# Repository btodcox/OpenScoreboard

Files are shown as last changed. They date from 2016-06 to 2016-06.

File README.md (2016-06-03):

#OpenScoreboard
## An Open Source Wireless Swimming Scoreboard that can be easily modified for other sports

OpenScoreboard is an Eagle Scout Project completed by David Cox in 2014.  The beneficiary/sponsoring organization was the Gleannloch Gators Swim Team.

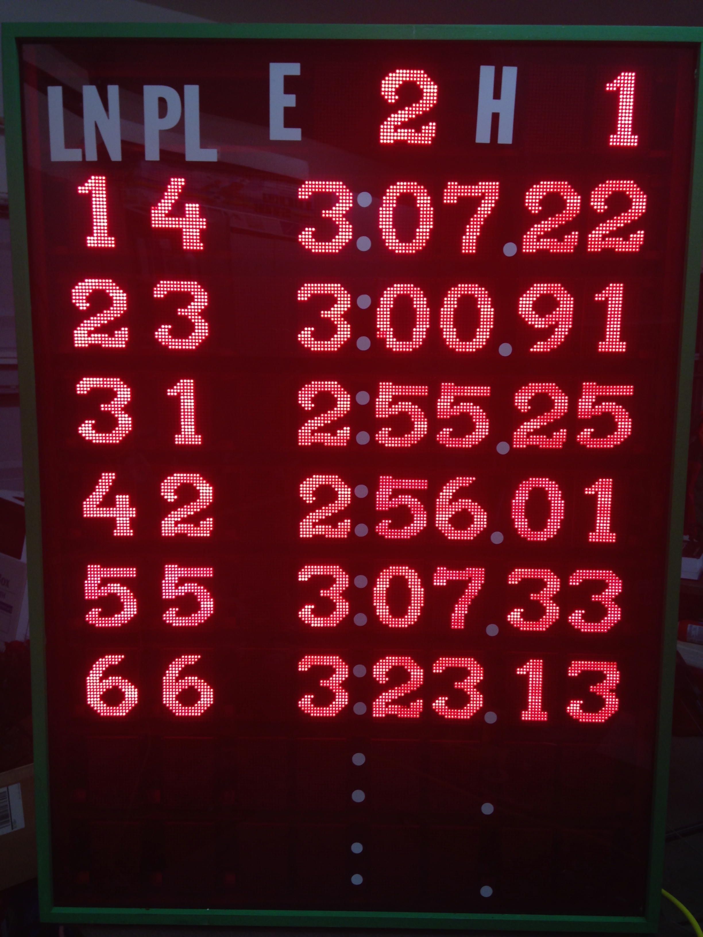
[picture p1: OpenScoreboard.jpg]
OpenScoreboard


The scoreboard hardware is designed around an Arduino derivative known as the Moteino from Felix Rusu at lowpowerlabs.com.  A program on a host PC implements a filewatcher.  When a new set of times is written to the hard drive of the host PC at the end of a completed heat, the program parses the times, calculates the swimmers tentative official time, determines the order of finish, and passes the data to a USB attached Moteino.  This Moteino then passes the information wirelessly to the scoreboard where it is displayed.  The results of a given heat are displayed until the next heat completes.  While this is a bit different than typical swimming scoreboards (which reset as soon as the next heat starts), it allows the coaches and swimmers to focus on the logistics of finishing one heat and beginning the next heat without having to hurriedly view the scoreboard.

License Info:

<br /><span xmlns:dct="http://purl.org/dc/terms/" property="dct:title">OpenScoreboard</span> by <a xmlns:cc="http://creativecommons.org/ns#" href="https://github.com/btodcox/Scoreboard" property="cc:attributionName" rel="cc:attributionURL">B Tod Cox & David Cox</a> is licensed under a <a rel="license" href="http://creativecommons.org/licenses/by-sa/4.0/">Creative Commons Attribution-ShareAlike 4.0 International License</a>. A copy of the license is available at the provided link. 

Portions of this project leverages other projects; attributions are included in the repository.

## Bill of Materials for 8-Lane Wireless Scoreboard

The estimated total cost for an 8-lane OpenScoreboard is ~$2500.

Custom PCA (a total of N+1 Custom PCAs are needed for an N-lane scoreboard)

*   9x Custom Scoreboard PCB (Eagle CAD files included in repository)
*   18X 74AHCT245D Octal Transceiver SOIC-20 ([Mouser 771-AHCT245D118](http://www.mouser.com/Search/ProductDetail.aspx?R=74AHCT245D,118virtualkey66800000virtualkey771-AHCT245D118))
*   2.1mm x 5.5mm DC barrel jack ([Mouser 163-7620E-E](http://www.mouser.com/Search/ProductDetail.aspx?R=163-7620E-Evirtualkey11180000virtualkey163-7620E-E))
*   18X dual row 2x5 0.1" female header ([Mouser 571-215309-5](http://www.mouser.com/Search/ProductDetail.aspx?R=215309-5virtualkey57100000virtualkey571-215309-5))
*   ~250X Breakaway 0.1" Male Headers ([Mouser 649-54101-S08-00](http://www.mouser.com/Search/ProductDetail.aspx?R=54101-S08-00virtualkey64910000virtualkey649-54101-S08-00))
*   18X 0.1uF 16V 10% X7R 0603 capacitor ([Mouser 80-C0603C104K4R7411](http://www.mouser.com/Search/ProductDetail.aspx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))

Electronic Parts

*   9X [Moteino Arduino clone with tranceiver and flash](http://lowpowerlab.com/moteino/#pinout)
*   1X [USB Moteino with transciever and no flash](http://lowpowerlab.com/moteino/#pinout)
*   68X 16x24 Red LED Matrix Panel Chainable HT1632C Driver ([Adafruit part #555](http://www.adafruit.com/products/555))
*   408X 1206 4RNet 27 Ohm 5% (to increase brightness of LED panels) ([Mouser 667-EXB-38V270JV](http://www.mouser.com/Search/ProductDetail.aspx?R=EXB-38V270JVvirtualkey66720000virtualkey667-EXB-38V270JV))
*   84X 2x5 IDC ribbon cable male connectors (need a different part number as I don't like the ones that I last ordered from Mouser)
*   ~50ft Flat Cables 28 AWG Ribbon .050 Zip 10 Cond ([Mouser 523-191-2801-110FT](http://www.mouser.com/Search/ProductDetail.aspx?R=191-2801-110FTvirtualkey52320000virtualkey523-191-2801-110FT))
*   4X 5V 10A switching power supply ([Adafruit part #658](http://www.adafruit.com/product/658))
*   3X 2-Way 2.1mm DC Barrel Jack Splitter Squid ([Adafruit part #1351](http://www.adafruit.com/product/1351))
*   Heavy gauge wire for connecting three lanes together (could not find a squid splitter long enough for Event/Heat + 2 lanes)
*   Surge protector
*   Mini-USB to USB cable
*   Small plastic box for USB Moteino

Case/Mechanical Structure

*   18X 3/4 in. x 1/2 in. x 36 in. Aluminum Flat Angle with 1/16 in. Thick ([Home Depot](http://www.homedepot.com/p/Crown-Bolt-3-4-in-x-1-2-in-x-36-in-Aluminum-Flat-Angle-with-1-16-in-Thick-43650/202183475)/Lowes/etc)
*   2X Steelworks 6-ft L x -3/4-in W x -3/4-in H Aluminum Plain Square Tube ([Lowes](http://www.lowes.com/pd_215691-37672-11388_0__)/Home Depot/etc)
*   Red Cast Acrylic (Aero-Shield Plastics in Houston)
*   1x6 Poplar S4S boards for case (Home Depot/Lowes/etc)
*   272X 4-40 x 1" female/female hex binding post ([Mouser 534-2205](http://www.mouser.com/Search/ProductDetail.aspx?R=2205virtualkey53400000virtualkey534-2205))
*   544x 4-40 3/8" phillips head screws ([Mouser 534-9901](http://www.mouser.com/Search/ProductDetail.aspx?R=9901virtualkey53400000virtualkey534-9901))
*   1-1/4 in. Coarse Zinc-Plated Steel Square-Head Pocket Screws (100-Pack) ([Home Depot](http://www.homedepot.com/p/Kreg-1-1-4-in-Coarse-Zinc-Plated-Steel-Square-Head-Pocket-Screws-100-Pack-SML-C125-100/100572559))
*   1X 1/4 in. 5 ft. x 5ft Baltic Birch Plywood-Grade A ([Houston Hardwoods](http://www.houstonhardwoods.net/))
*   Paint for wood (less than 1/2 pint is needed to cover wood)
*   Exterior grade urethane for back of plywood
*   Black matte spray paint for interior of plywood and aluminum

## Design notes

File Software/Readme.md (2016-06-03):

# Scoreboard code

* Host PC code is written in C# and is provided as a Visual Studio project.
* Moteino code compiles with the standard Arduino Development Environment.
    * Installation of appropriate libraries from lowpowerlabs github respositories is required.

* Preliminaries for Moteinos:
	* Clear eeprom on each Moteino used for lane displays
	* Program location 0 of eeprom with "address" of lane for Moteinos for each lane
    	* Address 0 is event/heat display
    	* Addresses 1-10 are Lanes 1-10, respectively
	* Base code goes on USB Moteino
	* RemoteHEWP code goes on Moteinos for each lane

## Programming the Moteinos in Scoreboard

* After initial programming of Moteinos with RemoteHEWP program, it is possible to wirelessly program them Moteinos WITHOUT disassembling the Scoreboard.  
* Wireless programming requires that a SPIFlash be installed on all Moteinos in the Scoreboard.
* More information about wireless programming is available at [lowpowerlabs.com](http://lowpowerlab.com/blog/category/moteino/wireless-programming/).

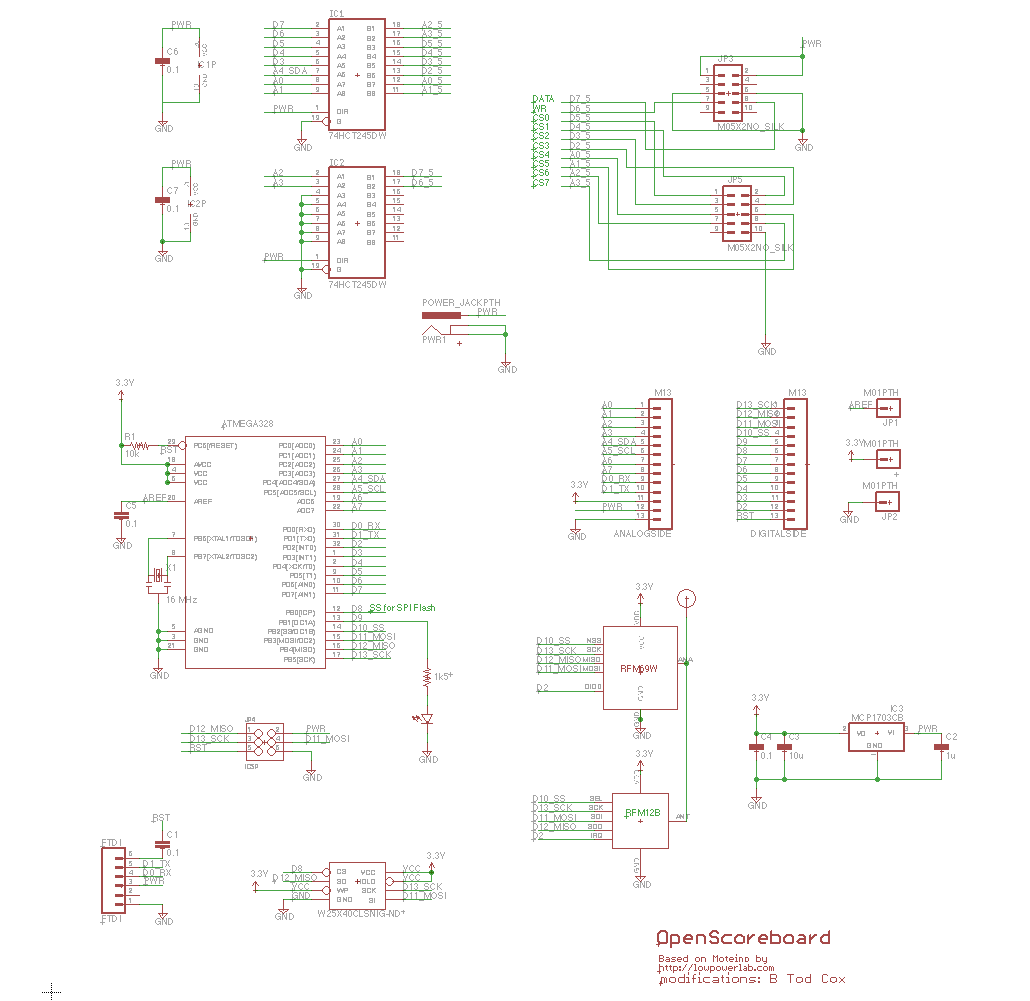
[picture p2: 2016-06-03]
Hardware/OpenScoreboard_PCB/OpenScoreboard.png

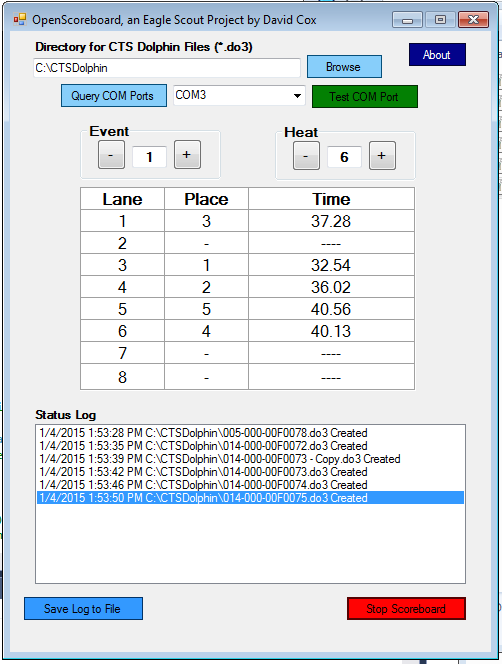
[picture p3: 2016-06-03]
Pics/OpenScoreboardHost.png

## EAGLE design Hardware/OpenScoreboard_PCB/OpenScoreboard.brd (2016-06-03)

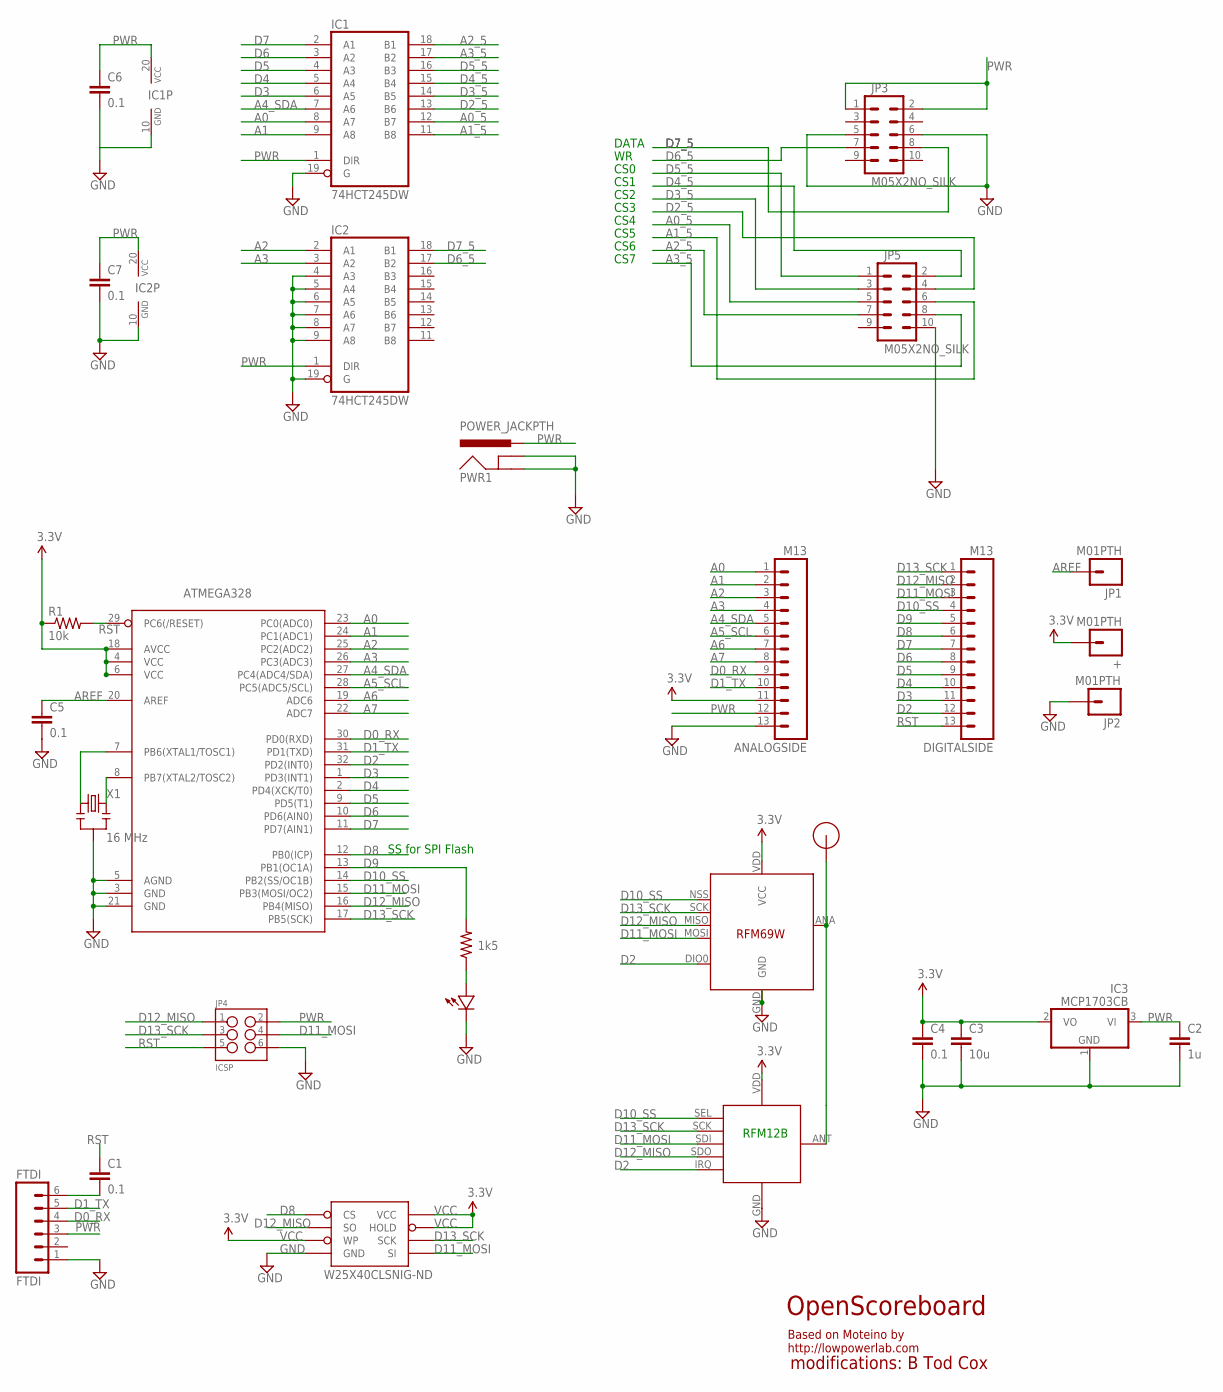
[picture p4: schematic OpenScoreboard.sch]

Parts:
+: M01PTH; 1X01
ANALOGSIDE: M13; 1X13
ATMEGA328: ATMega-328; TQFP32-08
C1, C4, C5, C6, C7: 0.1; 0603-CAP
C2: 1u; 0603-CAP
C3: 10u; 0805-CAP
DIGITALSIDE: M13; 1X13
FTDI: FTDI; 1X06
IC1, IC2: 74HCT245DW; SO20W
IC3: MCP1703CB; SOT23
JP1, JP2: M01PTH; 1X01
JP3, JP5: M05X2NO_SILK; 2X5_NOSILK
JP4: ICSP; 2X3_POGO
PWR1: POWER_JACKPTH; POWER_JACK_PTH
R1: 10k; 0603-RES
R2: 1k5; 0603-RES
RFM12B: RFM12B_MINPADS; RFM12B-MINPADS
U$1: RFM12B_ANTENNA; RFM12B-ANTENNA
U$2: LED0603; 0603-LED
U$5: RFM69; RFM69W-MINPADS
W25X40CLSNIG-ND: AT25F512BWIDE_5.3MM; SO08WIDE
X1: 16 MHz; RESONATOR-SMD

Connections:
A0: ANALOGSIDE.1, ATMEGA328.23 (PC0(ADC0)), IC1.8 (A7)
A0_5: IC1.12 (B7), JP5.5
A1: ANALOGSIDE.2, ATMEGA328.24 (PC1(ADC1)), IC1.9 (A8)
A1_5: IC1.11 (B8), JP5.6
A2: ANALOGSIDE.3, ATMEGA328.25 (PC2(ADC2)), IC2.2 (A1)
A2_5: IC1.18 (B1), JP5.7
A3: ANALOGSIDE.4, ATMEGA328.26 (PC3(ADC3)), IC2.3 (A2)
A3_5: IC1.17 (B2), JP5.8
A4_SDA: ANALOGSIDE.5, ATMEGA328.27 (PC4(ADC4/SDA)), IC1.7 (A6)
A5_SCL: ANALOGSIDE.6, ATMEGA328.28 (PC5(ADC5/SCL))
A6: ANALOGSIDE.7, ATMEGA328.19 (ADC6)
A7: ANALOGSIDE.8, ATMEGA328.22 (ADC7)
AREF: ATMEGA328.20 (AREF), C5.1, JP1.1
D0_RX: ANALOGSIDE.9, ATMEGA328.30 (PD0(RXD)), FTDI.4
D1_TX: ANALOGSIDE.10, ATMEGA328.31 (PD1(TXD)), FTDI.5
D2: ATMEGA328.32 (PD2(INT0)), DIGITALSIDE.12, RFM12B.IRQ, U$5.DIO0
D2_5: IC1.13 (B6), JP5.4
D3: ATMEGA328.1 (PD3(INT1)), DIGITALSIDE.11, IC1.6 (A5)
D3_5: IC1.14 (B5), JP5.3
D4: ATMEGA328.2 (PD4(XCK/T0)), DIGITALSIDE.10, IC1.5 (A4)
D4_5: IC1.15 (B4), JP5.2
D5: ATMEGA328.9 (PD5(T1)), DIGITALSIDE.9, IC1.4 (A3)
D5_5: IC1.16 (B3), JP5.1
D6: ATMEGA328.10 (PD6(AIN0)), DIGITALSIDE.8, IC1.3 (A2)
D6_5: IC2.17 (B2), JP3.7
D7: ATMEGA328.11 (PD7(AIN1)), DIGITALSIDE.7, IC1.2 (A1)
D7_5: IC2.18 (B1), JP3.8
D8: ATMEGA328.12 (PB0(ICP)), DIGITALSIDE.6, W25X40CLSNIG-ND.1 (CS)
D9: ATMEGA328.13 (PB1(OC1A)), DIGITALSIDE.5, R2.2
D10_SS: ATMEGA328.14 (PB2(SS/OC1B)), DIGITALSIDE.4, RFM12B.SEL, U$5.NSS (SEL)
D11_MOSI: ATMEGA328.15 (PB3(MOSI/OC2)), DIGITALSIDE.3, JP4.P$4 (4), RFM12B.SDI (SDI/MOSI), U$5.MOSI, W25X40CLSNIG-ND.5 (SI)
D12_MISO: ATMEGA328.16 (PB4(MISO)), DIGITALSIDE.2, JP4.P$1 (1), RFM12B.SDO (SDO/MISO), U$5.MISO, W25X40CLSNIG-ND.2 (SO)
D13_SCK: ATMEGA328.17 (PB5(SCK)), DIGITALSIDE.1, JP4.P$3 (3), RFM12B.SCK, U$5.SCK, W25X40CLSNIG-ND.6 (SCK)
GND: ANALOGSIDE.13, ATMEGA328.3 (GND), ATMEGA328.5 (AGND), ATMEGA328.21 (GND), C2.2, C3.2, C4.2, C5.2, C6.2, C7.2, FTDI.1, IC1.10 (GND), IC1.19 (G), IC2.4 (A3), IC2.5 (A4), IC2.6 (A5), IC2.7 (A6), IC2.8 (A7), IC2.9 (A8), IC2.10 (GND), IC2.19 (G), IC3.1 (GND), JP2.1, JP3.5, JP3.6, JP4.P$6 (6), JP5.10, PWR1.GND, PWR1.GNDBREAK, RFM12B.GND, U$2.MINUS, U$5.GND, W25X40CLSNIG-ND.4 (GND), X1.2
unnamed: ATMEGA328.7 (PB6(XTAL1/TOSC1)), X1.1
unnamed: R2.1, U$2.PLUS
unnamed: RFM12B.ANT, U$1.P$1, U$5.ANA (ANT)
unnamed: C1.2, FTDI.6
unnamed: ATMEGA328.8 (PB7(XTAL2/TOSC2)), X1.3
PWR: ANALOGSIDE.12, C2.1, C6.1, C7.1, FTDI.3, IC1.1 (DIR), IC1.20 (VCC), IC2.1 (DIR), IC2.20 (VCC), IC3.3 (VI), JP3.1, JP3.2, JP4.P$2 (2), PWR1.PWR
RST: ATMEGA328.29 (PC6(/RESET)), C1.1, DIGITALSIDE.13, JP4.P$5 (5), R1.2
VCC: +.1, ANALOGSIDE.11, ATMEGA328.4 (VCC), ATMEGA328.6 (VCC), ATMEGA328.18 (AVCC), C3.1, C4.1, IC3.2 (VO), R1.1, RFM12B.VDD, U$5.VDD (VCC), W25X40CLSNIG-ND.3 (WP), W25X40CLSNIG-ND.7 (HOLD), W25X40CLSNIG-ND.8 (VCC)

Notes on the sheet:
OpenScoreboard
modifications: B Tod Cox
Based on Moteino by http://lowpowerlab.com
RFM12B
SS for SPI Flash
DATA
CS0
CS1
CS2
CS3
CS4
CS5
CS6
CS7

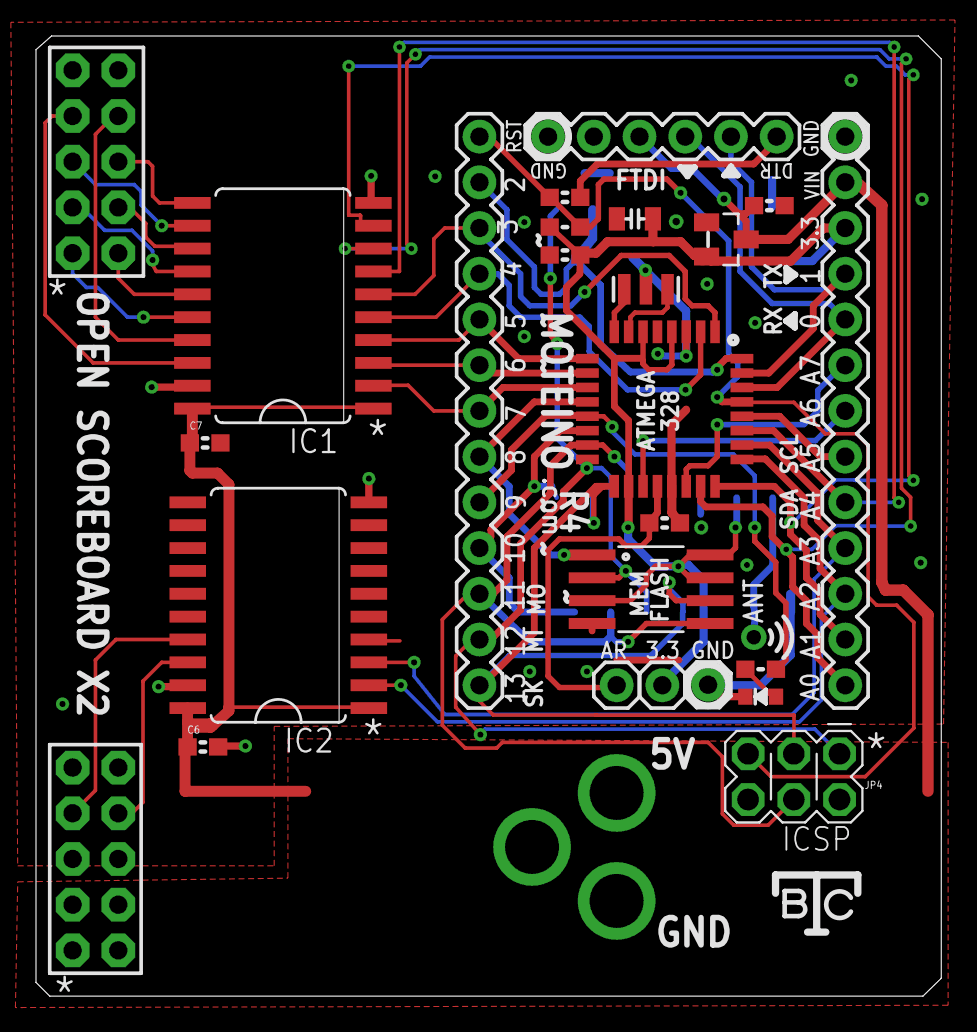
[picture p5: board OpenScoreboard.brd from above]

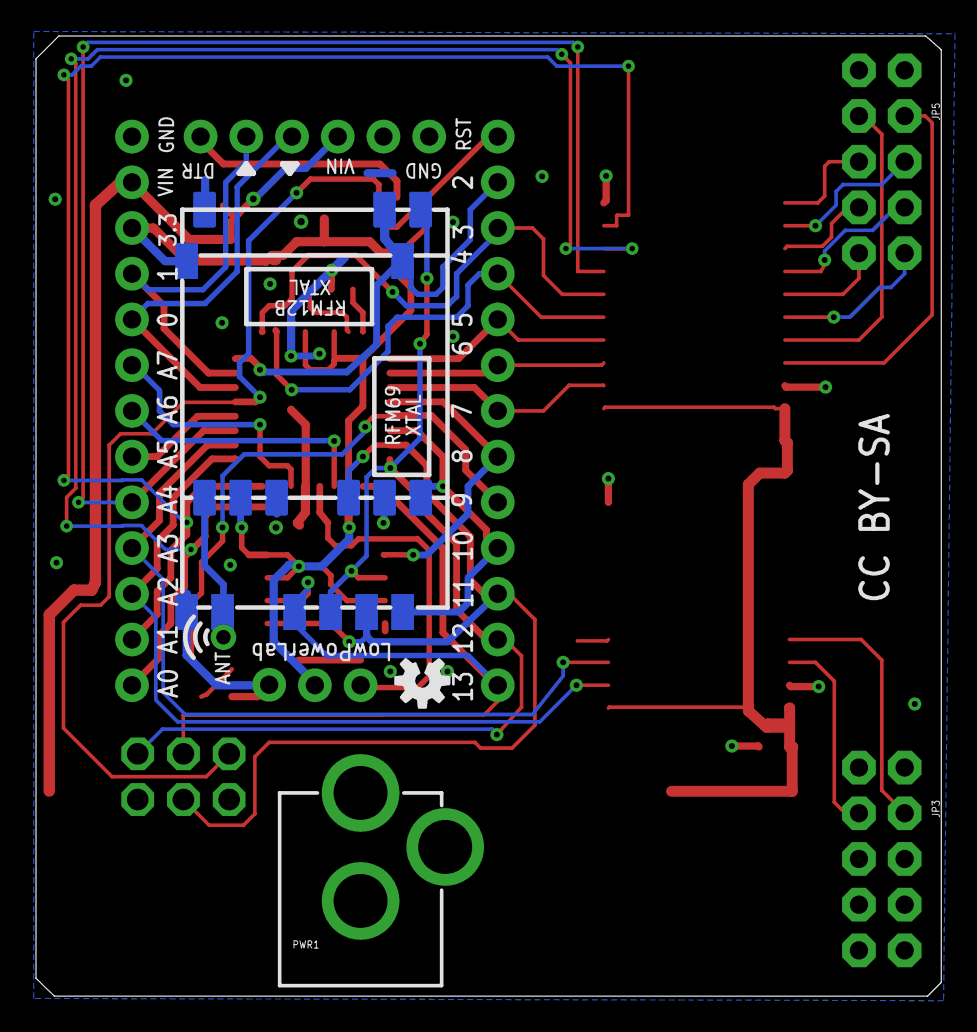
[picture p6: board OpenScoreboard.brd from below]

Board: 2 copper layers, 50.3 x 53.3 mm, 30 parts (6 on the bottom side), 42 nets.

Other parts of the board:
U$3: OSHW-LOGO-S

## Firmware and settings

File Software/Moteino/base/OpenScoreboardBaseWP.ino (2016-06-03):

/*
 * OpenScoreboard is an Eagle Scout project by David Cox
 *
 *
 * portions of code are:
 * Copyright (c) 2013 by Felix Rusu <felix@lowpowerlab.com>
 *
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
 *
 * additional code for a scoreboard is 
 * Copyright (c) 2014-15 by B Tod Cox & David Cox  
 *  all rights reserved.
 
// This sketch is an example of how wireless programming can be achieved with a Moteino
// that was loaded with a custom 1k Optiboot that is capable of loading a new sketch from
// an external SPI flash chip
// This is the GATEWAY node, it does not need a custom Optiboot nor any external FLASH memory chip
// (ONLY the target node will need those)
// The sketch includes logic to receive the new sketch from the serial port (from a host computer) and 
// transmit it wirelessly to the target node
// The handshake protocol that receives the sketch from the serial port 
// is handled by the SPIFLash/WirelessHEX69 library, which also relies on the RFM12B library
// These libraries and custom 1k Optiboot bootloader for the target node are at: http://github.com/lowpowerlab

#include <RFM69.h>
#include <SPI.h>
#include <SPIFlash.h>
#include <WirelessHEX69.h>

#define NETWORKID          124  //what network this node is on
#define NODEID               16  //this node's ID, should be unique among nodes on this NETWORKID
//Match frequency to the hardware version of the radio on your Moteino (uncomment one):
//#define FREQUENCY   RF69_433MHZ
//#define FREQUENCY   RF69_868MHZ
#define FREQUENCY     RF69_915MHZ
#define ENCRYPTKEY "GatorsEncryptKey" //(16 bytes of your choice - keep the same on all encrypted nodes)
//#define IS_RFM69HW            //uncomment only for RFM69HW! Leave out if you have RFM69W!

#define LED         9
#define SERIAL_BAUD 115200
#define ACK_TIME    50  // # of ms to wait for an ack
#define TIMEOUT     3000

RFM69 radio;
char c = 0;
char input[64]; //serial input buffer
byte targetID=0;

void setup(){
  Serial.begin(SERIAL_BAUD);
  radio.initialize(FREQUENCY,NODEID,NETWORKID);
  radio.encrypt(ENCRYPTKEY); //OPTIONAL
#ifdef IS_RFM69HW
  radio.setHighPower(); //only for RFM69HW!
#endif
  Serial.println("Start wireless gateway...");
}

void loop(){
  byte inputLen = readSerialLine(input, 10, 64, 100); //readSerialLine(char* input, char endOfLineChar=10, byte maxLength=64, uint16_t timeout=1000);
  
  if (inputLen==4 && input[0]=='F' && input[1]=='L' && input[2]=='X' && input[3]=='?') {
    if (targetID==0)
      Serial.println("TO?");
    else
      CheckForSerialHEX((byte*)input, inputLen, radio, targetID, TIMEOUT, ACK_TIME, true);
  }
  else if (inputLen>3 && inputLen<=6 && input[0]=='T' && input[1]=='O' && input[2]==':')
  {
    byte newTarget=0;
    for (byte i = 3; i<inputLen; i++) //up to 3 characters for target ID
      if (input[i] >=48 && input[i]<=57)
        newTarget = newTarget*10+input[i]-48;
      else
      {
        newTarget=0;
        break;
      }
    if (newTarget>0)
    {
      targetID = newTarget;
      Serial.print("TO:");
      Serial.print(newTarget);
      Serial.println(":OK");
    }
    else
    {
      Serial.print(input);
      Serial.print(":INV");
    }
  }
  else if ( input[0]=='O' && input[1]=='S' && input[2]=='B' &&  input[3]==' ' ){ // check for OpenScoreboard packet
     int lane=atoi(input+4); //get lane number to see if lane info/event-heat info/or display clear
     switch(lane){
       case 0:   Serial.println("Event Heat update");
                 radio.send(lane,input,inputLen);
                 break;
       case 15:
                 Serial.println("Clear Display");
                 for (int ii=1; ii <= 8; ii++){
                   radio.send(ii, "OSB          ",13);
                 }
                 break;
       default:
                 Serial.println(input);
                 radio.send(lane, input, inputLen);
     }
  }
  else if (inputLen>0) { //just echo back
    Serial.print("SERIAL IN > ");Serial.println(input);
  }

  if (radio.receiveDone())
  {
    for (byte i = 0; i < radio.DATALEN; i++)
      Serial.print((char)radio.DATA[i]);
    
    if (radio.ACK_REQUESTED)
    {
      radio.sendACK();
      Serial.print(" - ACK sent");
    }
    
    Serial.println();
  }
  Blink(LED,5); //heartbeat
}

void Blink(byte PIN, int DELAY_MS)
{
  pinMode(PIN, OUTPUT);
  digitalWrite(PIN,HIGH);
  delay(DELAY_MS);
  digitalWrite(PIN,LOW);
}

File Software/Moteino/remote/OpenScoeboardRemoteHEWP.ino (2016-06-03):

/*
 * OpenScoreboard is an Eagle Scout project by David Cox
 *
 *
 * portions of code are:
 * Copyright (c) 2013 by Felix Rusu <felix@lowpowerlab.com>
 *
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
 *
 * additional code for a scoreboard is 
 * Copyright (c) 2014-15 by B Tod Cox & David Cox  
 *  all rights reserved.

// This sketch is an example of how wireless programming can be achieved with a Moteino
// that was loaded with a custom 1k Optiboot that is capable of loading a new sketch from
// an external SPI flash chip
// The sketch includes logic to receive the new sketch 'over-the-air' and store it in
// the FLASH chip, then restart the Moteino so the bootloader can continue the job of
// actually reflashing the internal flash memory from the external FLASH memory chip flash image
// The handshake protocol that receives the sketch wirelessly by means of the RFM69 radio
// is handled by the SPIFLash/WirelessHEX69 library, which also relies on the RFM69 library
// These libraries and custom 1k Optiboot bootloader are at: http://github.com/lowpowerlab

#include "HT1632n.h"
#include "Adafruit_GFX.h"
#include "OSBfont.h"
#include "glcdfontn.c"

#include <EEPROM.h>

#include <RFM69.h>
#include <SPI.h>
#include <SPIFlash.h>
#include <avr/wdt.h>
#include <WirelessHEX69.h>

//#define MYID        1       // node ID used for this unit
int my_id;  //no longer a define so that can read value from eeprom and have same program for all lanes
#define NETWORKID   124
//Match frequency to the hardware version of the radio on your Moteino (uncomment one):
//#define FREQUENCY   RF69_433MHZ
//#define FREQUENCY   RF69_868MHZ
#define FREQUENCY     RF69_915MHZ
#define IS_RFM69HW  //uncomment only for RFM69HW! Leave out if you have RFM69W!
#define SERIAL_BAUD 115200
#define ACK_TIME    50  // # of ms to wait for an ack
#define ENCRYPTKEY  "GatorsEncryptKey"
#define LED         9
#define BLINKPERIOD 200

RFM69 radio;
char input = 0;
long lastPeriod = -1;

/////////////////////////////////////////////////////////////////////////////
// flash(SPI_CS, MANUFACTURER_ID)
// SPI_CS          - CS pin attached to SPI flash chip (8 in case of Moteino)
// MANUFACTURER_ID - OPTIONAL, 0x1F44 for adesto(ex atmel) 4mbit flash
//                             0xEF30 for windbond 4mbit flash
//                             0xEF40 for windbond 16/64mbit flash
/////////////////////////////////////////////////////////////////////////////
SPIFlash flash(8, 0xEF30); //EF30 for windbond 4mbit flash

//Scoreboard stuff
/* pinout for reworked Scoreboard X2 */
#define DA   A2 //data pin
#define WR   A3 //write strobe
#define CS1  5  //chip selects
#define CS2  4
#define CS3  3
#define CS4  A4
#define CS5  A0
#define CS6  A1
#define CS7  7
#define CS8  6

#define NUM_DISP 8 // number of LED matrices present

// use this line for single matrix
//HT1632LEDMatrix matrix = HT1632LEDMatrix(DATA, WR, CS1, CS2);
// use this line for two matrices!
HT1632LEDMatrix matrix = HT1632LEDMatrix(DA, WR, CS1, CS2, CS3, CS4, CS5, CS6, CS7, CS8);
 

void setup(){
  my_id = EEPROM.read(0);  // node id is stored in EEPROM location 0
  pinMode(LED, OUTPUT);
  Serial.begin(SERIAL_BAUD);
  radio.initialize(FREQUENCY,my_id,NETWORKID);
  radio.encrypt(ENCRYPTKEY); //OPTIONAL
#ifdef IS_RFM69HW
  radio.setHighPower(); //only for RFM69HW!
#endif
  Serial.print("Start node...");

  if (flash.initialize())
    Serial.println("SPI Flash Init OK!");
  else
    Serial.println("SPI Flash Init FAIL!");
    
  matrix.begin(HT1632_COMMON_16NMOS); 
  matrix.clearScreen();
  delay(500*my_id);  //delay so that each panel cycles through all on state
  matrix.fillScreen();
  delay(500);
  matrix.clearScreen();
  matrix.setTextSize(1);
  matrix.setTextColor(1);
  matrix.setCursor(0,0); 
  matrix.print("X2 ");
  matrix.print(my_id);
  matrix.writeScreen();
  delay(2000);
  matrix.setBrightness(15);
  matrix.clearScreen();
}

void loop(){
  // This part is optional, useful for some debugging.
  // Handle serial input (to allow basic DEBUGGING of FLASH chip)
  // ie: display first 256 bytes in FLASH, erase chip, write bytes at first 10 positions, etc
  if (Serial.available() > 0) {
    input = Serial.read();
    if (input == 'd') //d=dump first page
    {
      Serial.println("Flash content:");
      int counter = 0;

      while(counter<=256){
        Serial.print(flash.readByte(counter++), HEX);
        Serial.print('.');
      }
      
      Serial.println();
    }
    else if (input == 'e')
    {
      Serial.print("Erasing Flash chip ... ");
      flash.chipErase();
      while(flash.busy());
      Serial.println("DONE");
    }
    else if (input == 'i')
    {
      Serial.print("DeviceID: ");
      Serial.println(flash.readDeviceId(), HEX);
    }
    else if (input == 'r')
    {
      Serial.print("Rebooting");
      resetUsingWatchdog(true);
    }
    else if (input == 'R')
    {
      Serial.print("RFM69 registers:");
      radio.readAllRegs();
    }
    else if (input >= 48 && input <= 57) //0-9
    {
      Serial.print("\nWriteByte("); Serial.print(input); Serial.print(")");
      flash.writeByte(input-48, millis()%2 ? 0xaa : 0xbb);
    }
  }
  
  // Check for existing RF data, potentially for a new sketch wireless upload
  // For this to work this check has to be done often enough to be
  // picked up when a GATEWAY is trying hard to reach this node for a new sketch wireless upload
  if (radio.receiveDone())
  {
    Serial.print("Got [");
    Serial.print(radio.SENDERID);
    Serial.print(':');
    Serial.print(radio.DATALEN);
    Serial.print("] > ");
    for (byte i = 0; i < radio.DATALEN; i++)
      Serial.print((char)radio.DATA[i]);
    Serial.println ();
    CheckForWirelessHEX(radio, flash, true);
    CheckForOSB();
    Serial.println();
  }
  
  ////////////////////////////////////////////////////////////////////////////////////////////
  // Real sketch code here, let's blink the onboard LED
  if ((int)(millis()/BLINKPERIOD) > lastPeriod)
  {
    lastPeriod++;
    digitalWrite(LED, lastPeriod%2);
  }
  ////////////////////////////////////////////////////////////////////////////////////////////
}
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

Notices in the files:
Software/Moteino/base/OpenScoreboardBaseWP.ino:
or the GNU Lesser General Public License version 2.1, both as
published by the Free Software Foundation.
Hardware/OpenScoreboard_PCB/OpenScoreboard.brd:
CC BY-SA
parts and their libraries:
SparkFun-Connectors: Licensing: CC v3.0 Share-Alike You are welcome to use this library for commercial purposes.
